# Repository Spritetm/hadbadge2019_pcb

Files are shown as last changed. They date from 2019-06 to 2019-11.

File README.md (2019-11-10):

Hackaday Supercon 2019 Badge: PCB/schematics
============================================

This repo contains the schematics and PCB artwork for the Hackaday Supercon 2019 badge. It isn't
as cleaned up yet as I want to be, but I hope it works as a reference. Note that there may be some
older text and other files floating around in the repo as well.

Known Issues
------------

There are some issues with the final release on the badge. They are collected here. If you find more,
feel free to open an issue.

* The PMOD connector I/O pins are reversed in contrast with the actual PMOD specification. As the
Vcc and GND pins are not affected, the connector is still PMOD-compatible. Only the badge silkscreen
and the schematics have the wrong pinout, the SoC and software is correct. 
(Ref [here](https://github.com/Spritetm/hadbadge2019_fpgasoc/issues/18) )

* The SAO connector is messed up: the SCL/SDA lines as well as GPIO1/GPIO2 are swapped. Both the net
names in the schematic as well as the silkscreen legend have this issue. Again, as Gnd and Vcc are in
the correct locations, this does not influence the functionality.

* The 8MHz clock oscillator is routed to a non-clock-capable GPIO. While Yosys/Nextpnr doesn't
have any real issues with this, the official lattice Diamond software will refuse to use this
as a clock pin. As a workaround, you may be able to route it to a clock-capable free pin, then use
the input from that pin as a clock. (Ref [here](https://github.com/Spritetm/hadbadge2019_fpgasoc/issues/12) )

* The buttons on the badge are not the intended 4.3mm model, but a larger one. This is caused 
by the wrong footprint; the footprint actually has the size of the button somewhere in the description, 
and the Chinese logistics guy dutifully went with that instead of the Taobao link or other things
indicating it needs to be 4.3mm.

* The badge cannot run from an USB power connection. This is intentional, as there's no nice way to
feed 5V into the system without adding a fair amount of extra power supply electronics.

License
-------

This hardware is licensed under [CC-BY-SA 3.0](http://creativecommons.org/licenses/by-sa/3.0/) 
A non-legalese summary would be that you're allowed to share and remix these designs, but you
should attribute me (Sprite_tm/Jeroen Domburg) for my work, and your new work should be licensed
under the same or a similar license. If this license doesn't work for your purposes, feel free
to contact me to discuss a different license. Also, optionally, if you do use these designs 
to build something, I would very much appreciate it if you could send me a copy.

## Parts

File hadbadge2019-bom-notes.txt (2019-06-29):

- J5 is for a LCD. This LCD is not in the BOM, but we would also like it to be in the quote. The
LCD is a ZYX Technology LQ032ALJV01 as sold here:
https://item.taobao.com/item.htm?spm=a1z09.2.0.0.67002e8dLTaCnr&id=43697704645&_u=h2c9d2uca587

- J11 is No Stuff.
- J3 is No Stuff
- R8, R19, R16 are No Stuff.

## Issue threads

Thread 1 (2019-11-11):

Need models for 3d output

softegg, 2019-11-11:
I'm trying to design an enclosure in advance of Hackaday Superconference, and although I can export a the PCB as a 3d model,  a lot of the 3d models are missing. It is much easier to construct an accurate enclosure if the parts that need holes or space in the enclosure, or button / switch tops are available and accurate.

A lot of the 3d models for parts like switches and the BGA part don’t seem to be part of the standard KiCAD distribution, and Googling isn’t turning them up.
So far, I’m looking at:
The buttons: SW_PUSH_6mm_H9.5mm.wrl The notes give a Taobao link, I suppose I should look it up, but it would be nice to not have to model it from scratch.
The connector for the screen (FH26W-45S-0.3SHW(60)) seems to have no model even listed, and there is not even a part on the board for the screen, so it seems. Found the part number (ZYX Technology LQ032ALJV01) in the BOM notes, so I looked that up. Although the manufacturer has a link, all it does is let you request a model.
The USB connector on J2: Connector_USB.3dshapes doesn’t contain USB_Micro-B_Amphenol, just other brands.
HDMI (!?) on J4 has no model. Seems to be Boom Precision HDMI-001.
The power switch doesn’t have a 3d model. I had to search to find what I think is a model number “Hroparts K3 12965”. I guess I have to build that one. Is it similar to some other part I might be able to find?
The BGA (not that important to model around, but nice for completeness): Lattice_caBGA-381_17.0x17.0mm_Layout20x20_P0.8mm_Ball0.4mm_Pad0.4mm_NSMD.wrl
The battery holders don’t have 3d models or model numbers, but they seem pretty generic, so maybe I can just use a standard one from something else and hope it fits.
The IR Receiver at U12 has no 3d model set. Seems to be RPM973-H11
Finally, speaker attached to J3, it would be good to know the part number

If some of these could be provided, it would make life a lot easier for me!

Spritetm, 2019-11-11:
FYI, I didn't add any 3d models to the PCB design myself, as I didn't need that feature. (I'd even have to look up how to do 3d models in the first place...) I'm afraid that what is in the repo is what you get...

softegg, 2019-11-11:
It just seemed like there were some parts that had models linked, implying that they exist, that aren't part of the standard distribution, and aren't included here.  Googling didn't turn them up. So I thought they might be living on your machine somehow, and perhaps you could share them?

Spritetm, 2019-11-11:
If they are, I have no idea how they got there, as I said I didn't add any models myself and my Kicad install is just a Debian apt-get install jobbie which I assume just pulls in the default libs.

softegg, 2019-11-11:
Can I get measurements on the display at least? Or a link to a datasheet with such? (And maybe the visible area?)
I've been googling, but I can't seem to find anything about LQ032ALJV01. I've found LQ35 and greater, but not this particular one.

Spritetm, 2019-11-11:
Yeah, the display is some obscure Chinesium, but hey, it was cheap and looks pretty good. I can probably give you measurements when I'm back home, this evening. Any other things you want me to put a pair of calipers against?

softegg, 2019-11-11:
Well, I've been substituting 3d models for other similar parts in absence of the actual parts and am pretty close to done save for the screen. I suspect that my HDMI port is probably too tall, so measuring that would be kind.
I'm currently using the model at https://grabcad.com/library/fci-hdmi-right-angle-header-1 in that place.
Also, I see in your notes that the manufacturer substituted a different button than the 4.3mm one you specified. Can you tell what size they actually used?

Spritetm, 2019-11-11:
HDMI connector has a datasheet [here](https://lcsc.com/product-detail/Audio-Video-Connectors_Boom-Precision-Elec-HDMI-001_C138388.html). (Link is on there, not sure if I can link it directly.)

LCD: Does [this sketch](http://j0h.nl/XPcB/full) give enough info? Note that the LCD is affixed to the PCB with double-sided foam tape of unknown thickness; I don't have any final badges here so I can't measure that.

softegg, 2019-11-13:
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
Made some progress!
How tall did the stem on the buttons end up being?
They seem quite close together...
I'm a little worried about the ports... they will be quite recessed in the case and I worry about the enclosure interfering with the cable housing.
I still need to model the backs of the buttons, lightpipe for LEDs, cartridge port and I/O access, but it is starting to look like something.

softegg, 2019-11-14:
Can I get the size of the stem on the buttons, please?
Also, is there a design for the cartridge PCB?

sphereinabox, 2019-11-15:
The buttons are 9.5mm or so tall when not clicked.

https://github.com/Spritetm/hadbadge2019_protoboard has the protoboard

softegg, 2019-11-15:
Thanks! I'll update the models. I'm already 3d printing them at the 4.3mm size, so I'll have to start the new print before I leave for Supercon. Maybe the current ones can be drilled out or something

Sorry I missed the presentation on them this morning; I was up till 6am working on getting this print going, and am still trying to finish the rest of the parts. I'll be there by 4pm, I hope!

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

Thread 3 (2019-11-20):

BOM / LCD part number

PTS93, 2019-11-20:
Do you have a full BOM?
Would love to look into possible replacement screens. Some specs and the drivers IC would be great.

Spritetm, 2019-11-21:
The display itself is an AUO H320QN01, I'm not 100% sure what version. Note that it probably does not 100% match anything you can find on the Internet, as I'm sure the chinese fab we got them from kinda assembled the display module from spare parts. I think the controller is a Samsung S6D05A1 chip; you probably want to compare that datasheet with the initialization sequence if you want to be 100% sure, though. The display originated [here](https://item.taobao.com/item.htm?spm=a1z09.2.0.0.67002e8dkyjVv9&id=43697704645&_u=l2c9d2uc25f4) but be aware that they changed the actual display to the Samsung controller later, so the pictures there are not matching what's on the badge.

PTS93, 2019-11-21:
Hm they do claim "Long-term supply". You mentioned at Supercon that they are likely not gonna be made that way again?

sqfmi, 2019-11-21:
I put together a BOM and cost estimate from the KiCad files: https://github.com/sqfmi/hadbadge2019_pcb/blob/master/hadbadge2019.csv

PTS93, 2019-11-21:
Awesome!

liamcadigan, 2020-02-17:
It would be great if we could get a copy of the BOM with part numbers instead of links to the website. Similar to the format described here https://www.inspectar.com/help-center-articles/creating-a-bom .

If that can be done we will upload it to the free version of inspectAR, an augmented reality tool for working on physical PCBs. Users will be able to request part details and view datasheets from Digi-Key natively within our application.

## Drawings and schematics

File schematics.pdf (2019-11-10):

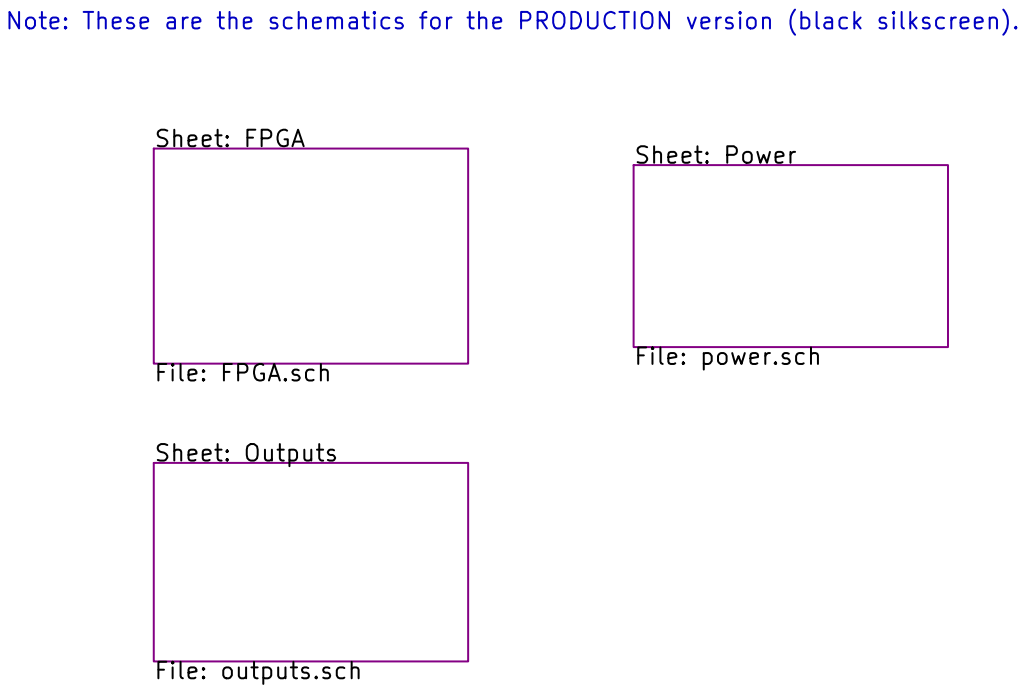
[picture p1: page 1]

Note: These are the schematics for the PRODUCTION version (black silkscreen).

File: hadbadge2019.sch Sheet: /
Id: 1/4 Title: Hackaday Badge 2019

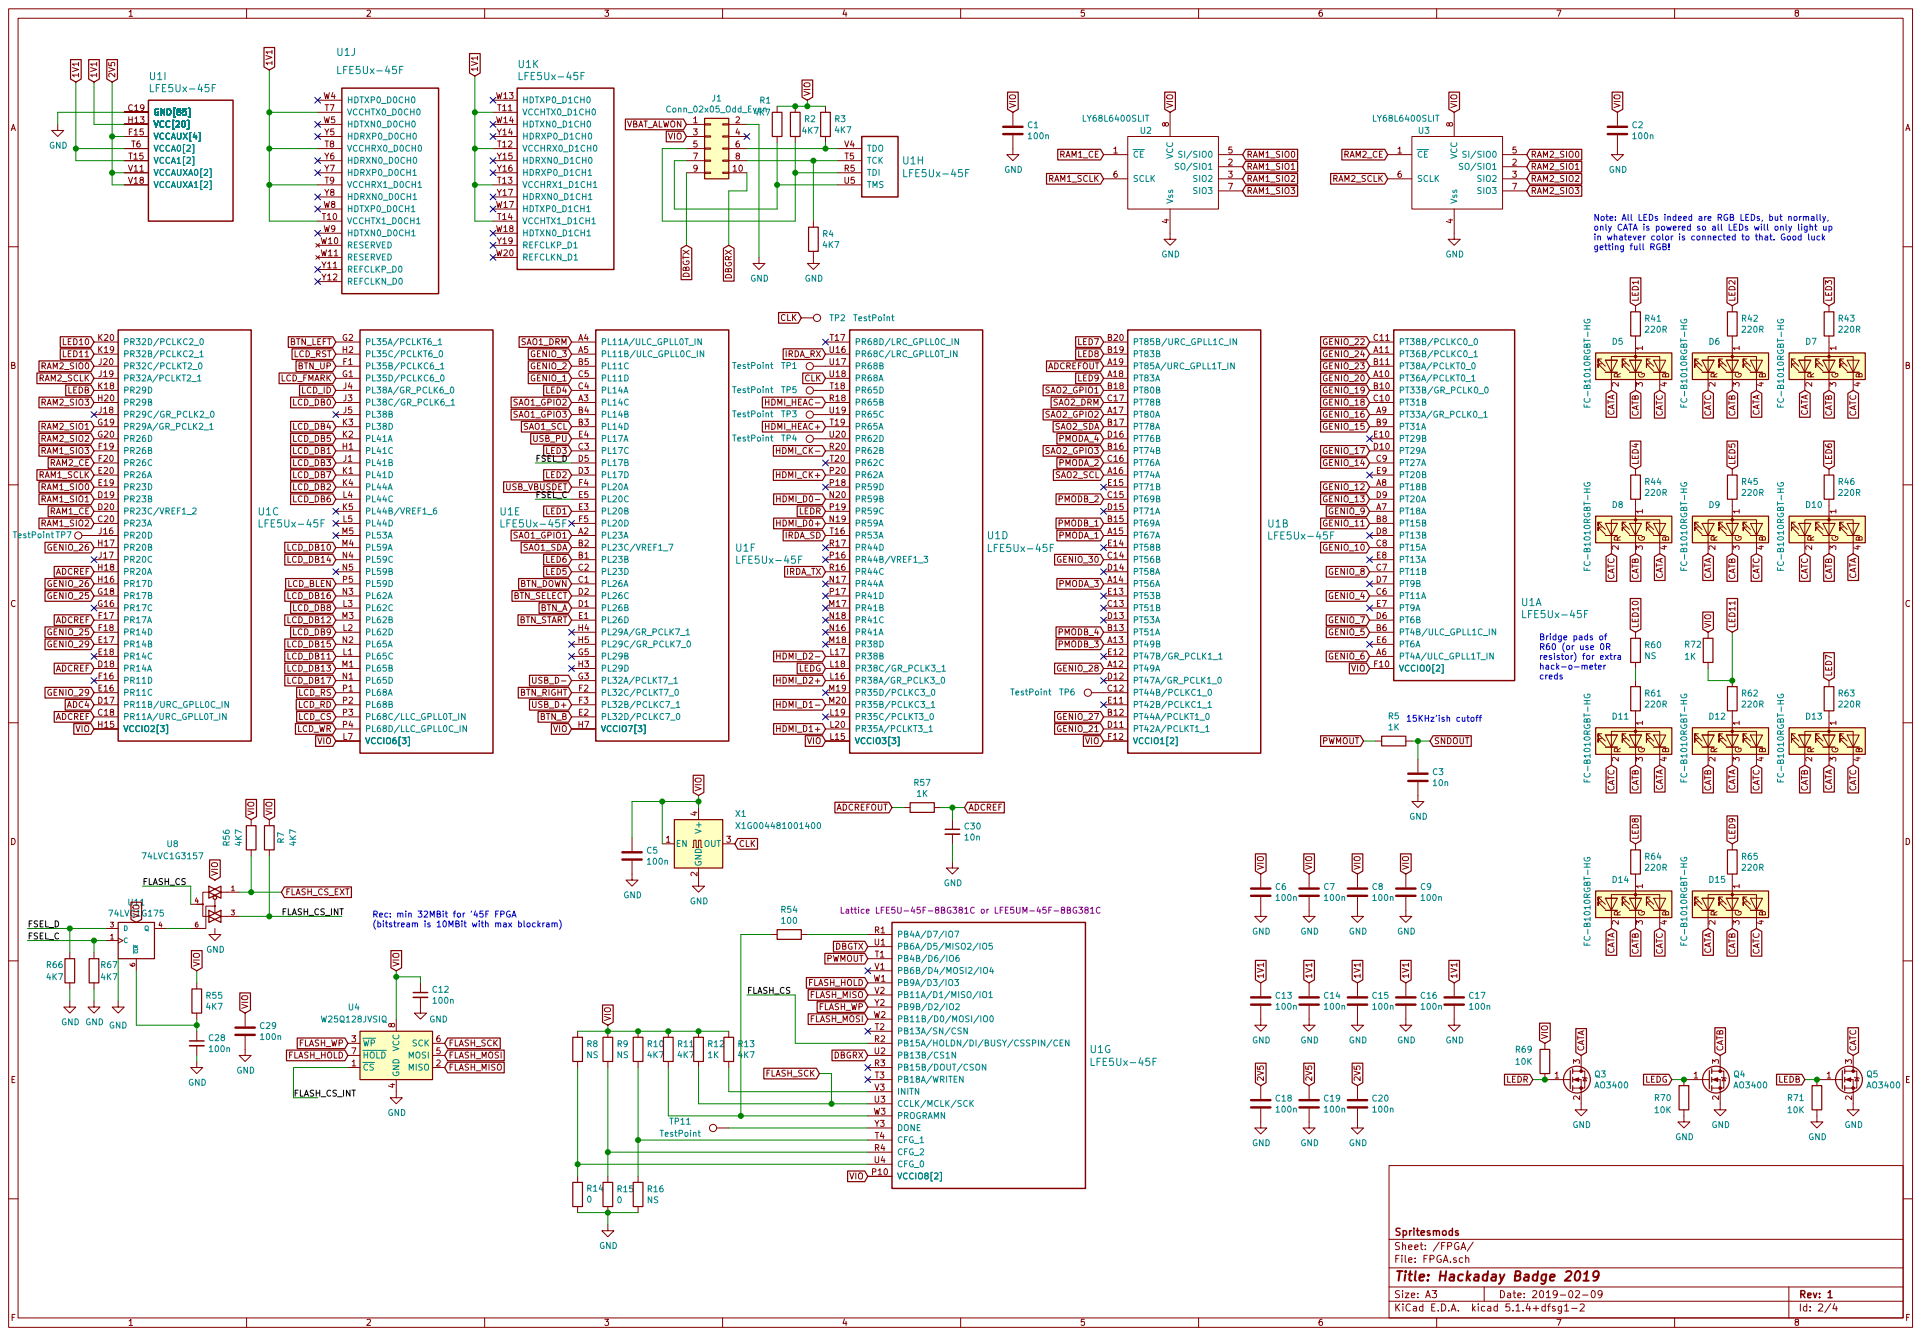
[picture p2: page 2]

Note: All LEDs indeed are RGB LEDs, but normally,
only CATA is powered so all LEDs will only light up
in whatever color is connected to that. Good luck getting full RGB!

Rec: min 32MBit for '45F FPGA

4 MOSI 5 SCK 6 HOLD 7 VCC

File: FPGA.sch Sheet: /FPGA/ Spritesmods C19

Id: 2/4 Title: Hackaday Badge 2019

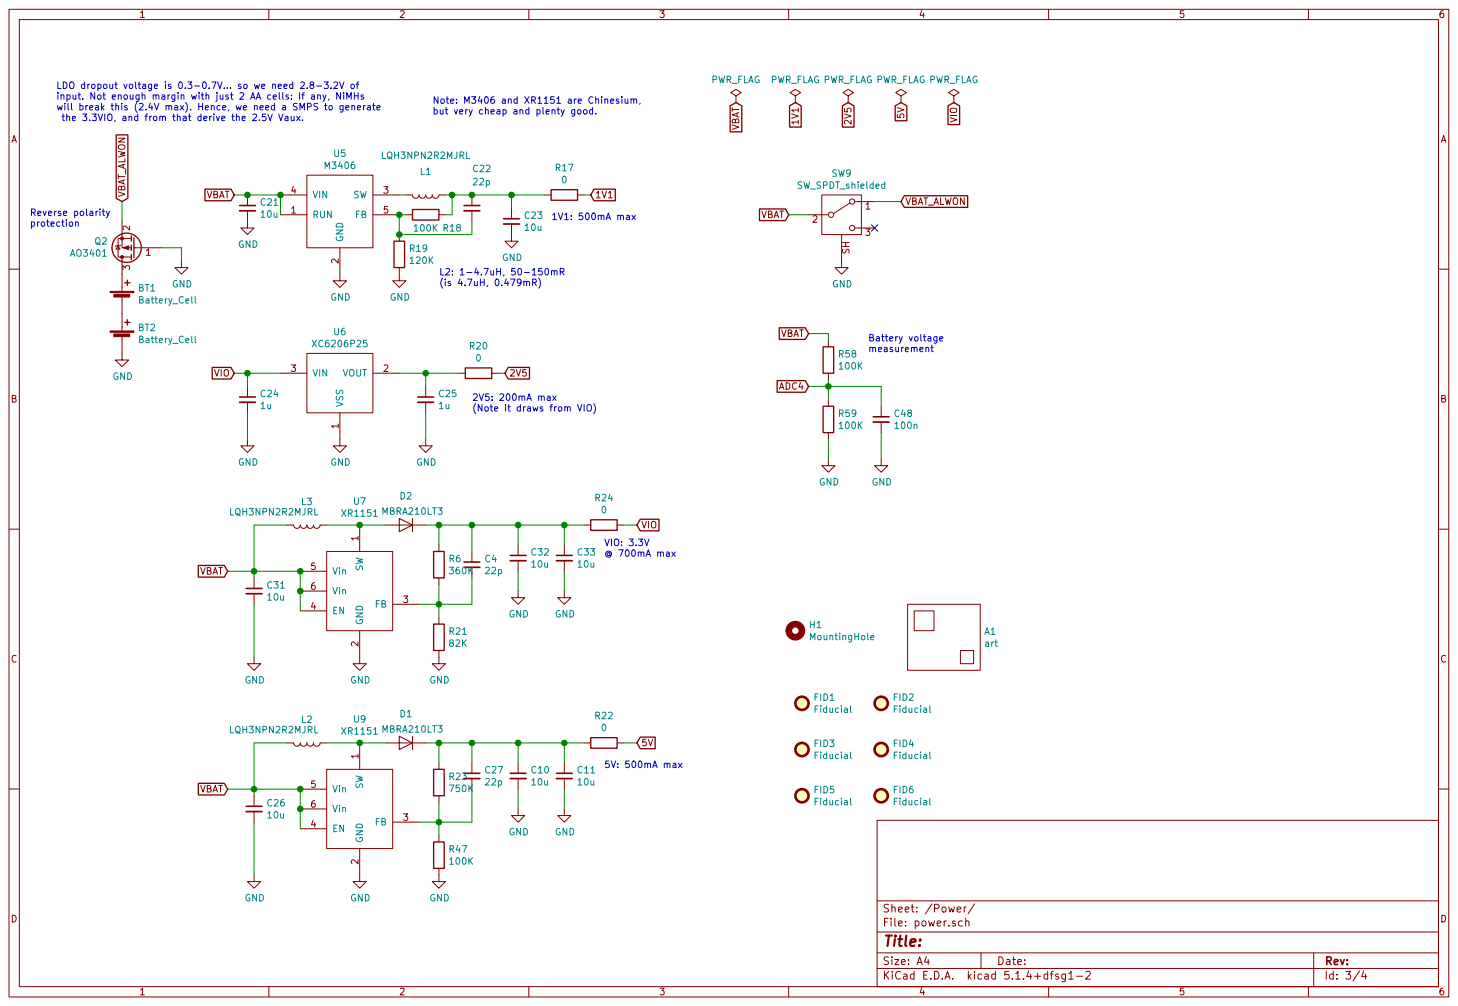
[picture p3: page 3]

LDO dropout voltage is 0.3-0.7V... so we need 2.8-3.2V of
input. Not enough margin with just 2 AA cells: If any, NiMHs
will break this (2.4V max). Hence, we need a SMPS to generate
the 3.3VIO, and from that derive the 2.5V Vaux.

PWR_FLAG PWR_FLAG PWR_FLAG
5V: 500mA max VIO: 3.3V @ 700mA max Note: M3406 and XR1151 are Chinesium, but very cheap and plenty good. 1V1: 500mA max 2V5: 200mA max

2 SW 3 VIN 4 FB 5 U5 M3406 GND GND
LQH3NPN2R2MJRL C24

(Note it draws from VIO) L2: 1-4.7uH, 50-150mR

2 FB 3 EN 4 Vin 5 Vin 6 U7 XR1151 GND
100K GND VSS

2 FB 3 EN 4 Vin 5 Vin 6 U9 XR1151 R23

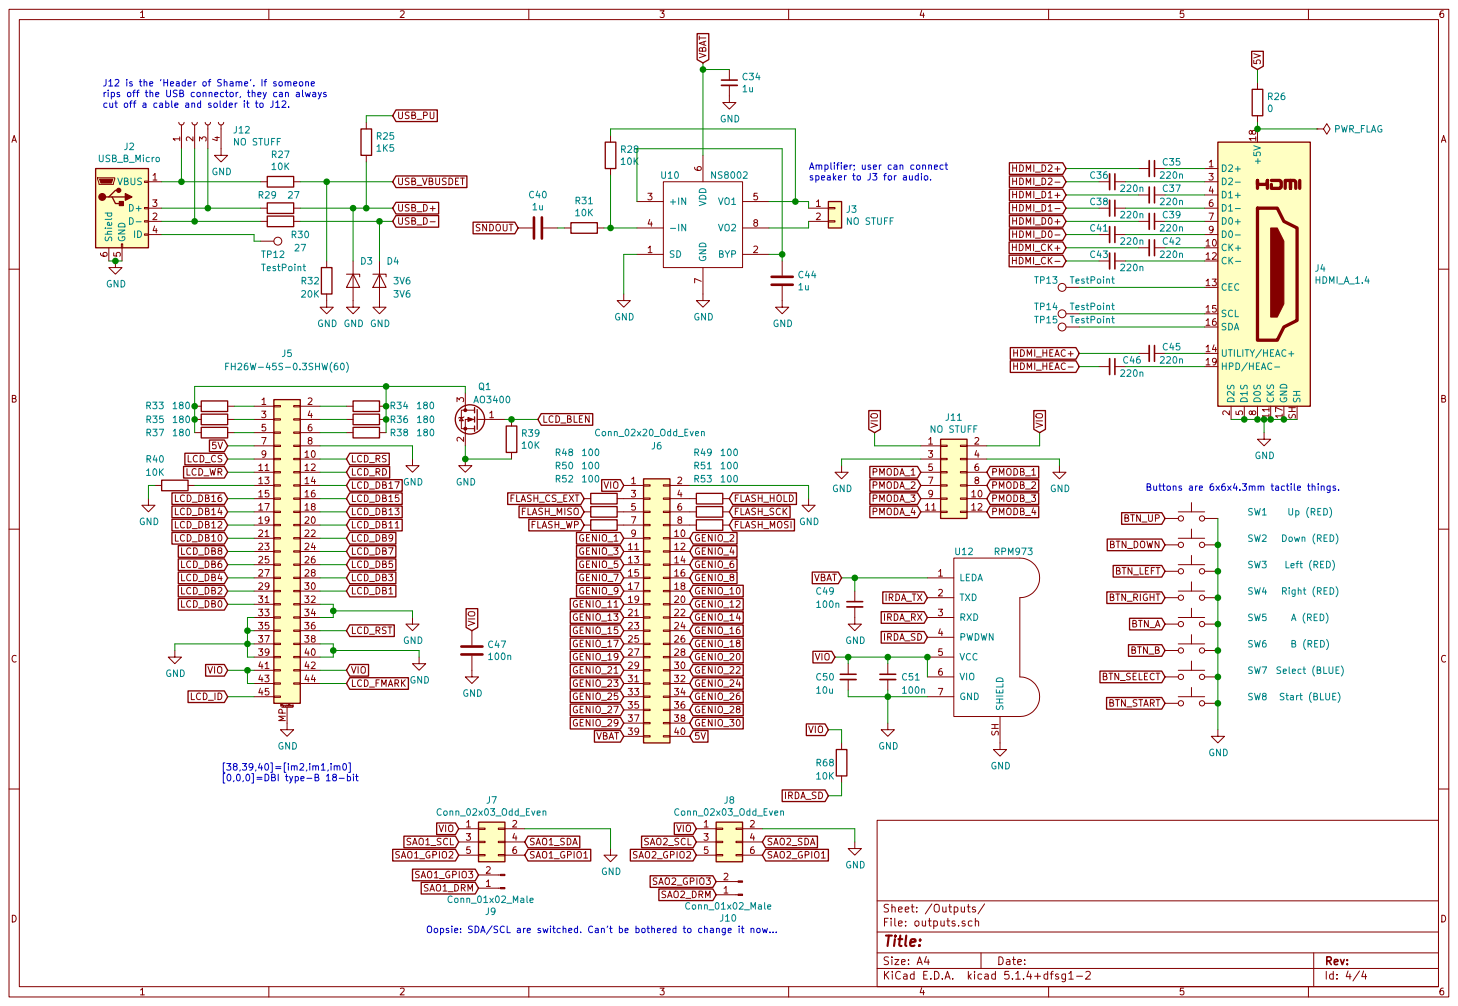
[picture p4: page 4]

J12 is the 'Header of Shame'. If someone
rips off the USB connector, they can always

Amplifier; user can connect
speaker to J3 for audio.

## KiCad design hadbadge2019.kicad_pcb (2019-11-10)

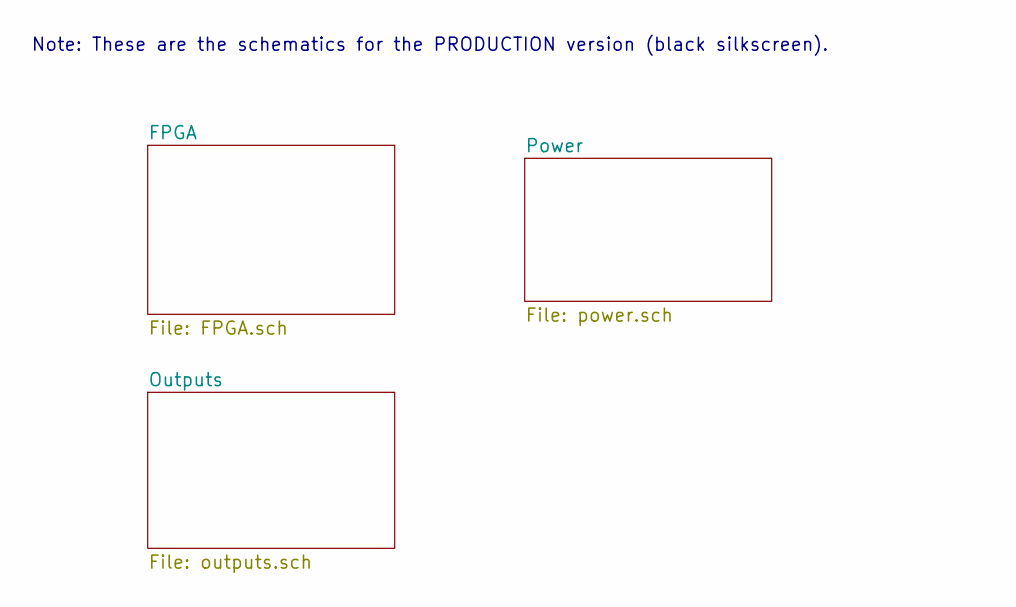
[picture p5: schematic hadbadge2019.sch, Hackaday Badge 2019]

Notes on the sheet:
Note: These are the schematics for the PRODUCTION version (black silkscreen).

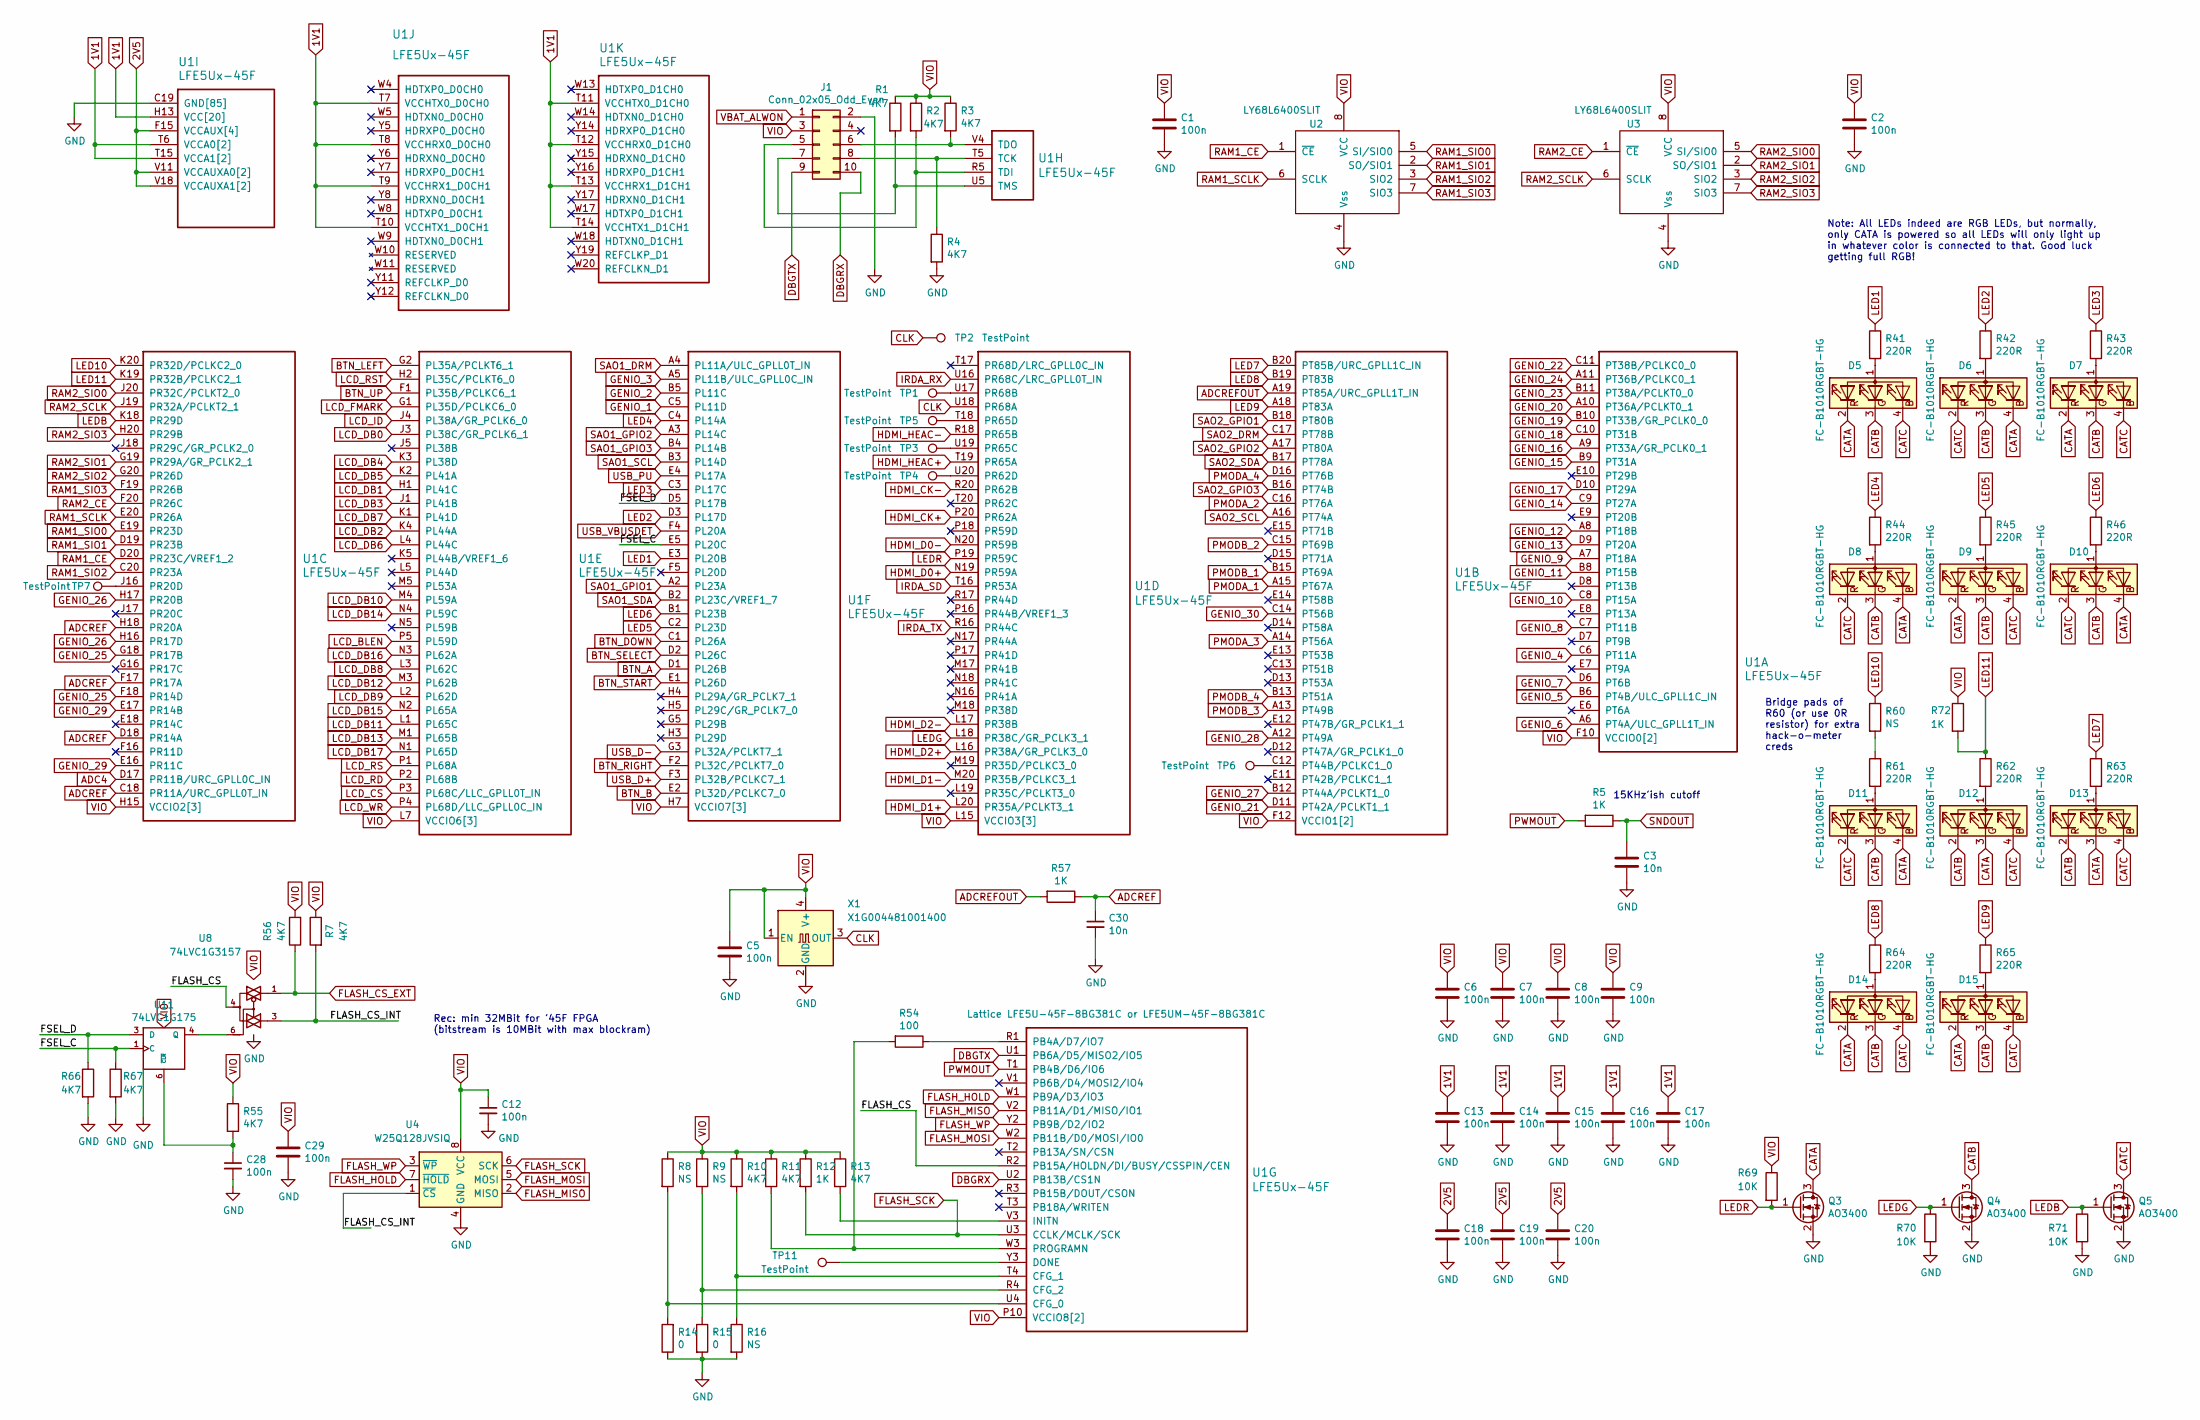
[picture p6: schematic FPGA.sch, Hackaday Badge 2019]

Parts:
C1, C2, C5, C6, C7, C8, C9, C12, C13, C14, C15, C16, C17, C18, C19, C20, C28, C29: 100n; C_0603_1608Metric
C3, C30: 10n; C_0603_1608Metric
D5, D6, D7, D8, D9, D10, D11, D12, D13, D14, D15: FC-B1010RGBT-HG
J1: Conn_02x05_Odd_Even; PinHeader_2x05_P2.54mm_Vertical
Q3, Q4, Q5: AO3400; SOT-23
R1, R2, R3, R4, R7, R10, R11, R13, R55, R56, R66, R67: 4K7; R_0603_1608Metric
R5, R12, R57, R72: 1K; R_0603_1608Metric
R8, R9, R16, R60: NS; R_0603_1608Metric
R14, R15: 0; R_0603_1608Metric
R41, R42, R43, R44, R45, R46, R61, R62, R63, R64, R65: 220R; R_0603_1608Metric
R54: 100; R_0603_1608Metric
R69, R70, R71: 10K; R_0603_1608Metric
TP1, TP2, TP3, TP4, TP5, TP6, TP7, TP11: TestPoint; TestPoint_Pad_D1.0mm
U1: LFE5Ux-45F; Lattice_caBGA-381_17.0x17.0mm_Layout20x20_P0.8mm_Ball0.4mm_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
U2, U3: LY68L6400SLIT; SSOP-8_3.9x5.05mm_P1.27mm
U4: W25Q128JVSIQ; SSOP-8_5.25x5.24mm_P1.27mm
U8: 74LVC1G3157; SOT-23-6
U11: 74LVC1G175; SOT-23-6
X1: X1G004481001400; Seiko_fp_crystal_SMD_7050-4Pin_7.0x5.0mm

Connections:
1V1: C13.1, C14.1, C15.1, C16.1, C17.1, U1.H8 (VCC[20]), U1.H9 (VCC[20]), U1.H10 (VCC[20]), U1.H11 (VCC[20]), U1.H12 (VCC[20]), U1.H13 (VCC[20]), U1.J8 (VCC[20]), U1.J13 (VCC[20]), U1.K8 (VCC[20]), U1.K13 (VCC[20]), U1.L8 (VCC[20]), U1.L13 (VCC[20]), U1.M8 (VCC[20]), U1.M13 (VCC[20]), U1.N8 (VCC[20]), U1.N9 (VCC[20]), U1.N10 (VCC[20]), U1.N11 (VCC[20]), U1.N12 (VCC[20]), U1.N13 (VCC[20]), U1.T6 (VCCA0[2]), U1.T7 (VCCHTX0_D0CH0), U1.T8 (VCCHRX0_D0CH0), U1.T9 (VCCHRX1_D0CH1), U1.T10 (VCCHTX1_D0CH1), U1.T11 (VCCHTX0_D1CH0), U1.T12 (VCCHRX0_D1CH0), U1.T13 (VCCHRX1_D1CH1), U1.T14 (VCCHTX1_D1CH1), U1.T15 (VCCA1[2]), U1.U6 (VCCA0[2]), U1.U15 (VCCA1[2]); also elsewhere on the board
2V5: C18.1, C19.1, C20.1, U1.F6 (VCCAUX[4]), U1.F15 (VCCAUX[4]), U1.P6 (VCCAUX[4]), U1.P15 (VCCAUX[4]), U1.V10 (VCCAUXA0[2]), U1.V11 (VCCAUXA0[2]), U1.V17 (VCCAUXA1[2]), U1.V18 (VCCAUXA1[2]); also elsewhere on the board
/FPGA/FLASH_CS: U1.R2 (PB15A/HOLDN/DI/BUSY/CSSPIN/CEN), U8.4
/FPGA/FLASH_CS_INT: R7.2, U4.1 (~CS), U8.3
/FPGA/FSEL_C: R67.1, U1.E5 (PL20C), U11.1 (C)
/FPGA/FSEL_D: R66.1, U1.D5 (PL17B), U11.3 (D)
ADC4: U1.D17 (PR11B/URC_GPLL0C_IN); also elsewhere on the board
ADCREF: C30.1, R57.1, U1.C18 (PR11A/URC_GPLL0T_IN), U1.D18 (PR14A), U1.F17 (PR17A), U1.H18 (PR20A)
ADCREFOUT: R57.2, U1.A19 (PT85A/URC_GPLL1T_IN)
BTN_A: U1.D1 (PL26B); also elsewhere on the board
BTN_B: U1.E2 (PL32D/PCLKC7_0); also elsewhere on the board
BTN_DOWN: U1.C1 (PL26A); also elsewhere on the board
BTN_LEFT: U1.G2 (PL35A/PCLKT6_1); also elsewhere on the board
BTN_RIGHT: U1.F2 (PL32C/PCLKT7_0); also elsewhere on the board
BTN_SELECT: U1.D2 (PL26C); also elsewhere on the board
BTN_START: U1.E1 (PL26D); also elsewhere on the board
BTN_UP: U1.F1 (PL35B/PCLKC6_1); also elsewhere on the board
CATA: D5.2 (RK), D6.4 (BK), D7.2 (RK), D8.4 (BK), D9.2 (RK), D10.4 (BK), D11.4 (BK), D12.3 (GK), D13.3 (GK), D14.2 (RK), D15.2 (RK), Q3.3 (D)
CATB: D5.3 (GK), D6.3 (GK), D7.3 (GK), D8.3 (GK), D9.3 (GK), D10.3 (GK), D11.3 (GK), D12.2 (RK), D13.2 (RK), D14.3 (GK), D15.3 (GK), Q4.3 (D)
CATC: D5.4 (BK), D6.2 (RK), D7.4 (BK), D8.2 (RK), D9.4 (BK), D10.2 (RK), D11.2 (RK), D12.4 (BK), D13.4 (BK), D14.4 (BK), D15.4 (BK), Q5.3 (D)
CLK: TP2.1, U1.U18 (PR68A), X1.3 (OUT)
DBGRX: J1.10, U1.U2 (PB13B/CS1N)
DBGTX: J1.9, U1.U1 (PB6A/D5/MISO2/IO5)
FLASH_CS_EXT: R56.1, U8.1; also elsewhere on the board
FLASH_HOLD: U1.W1 (PB9A/D3/IO3), U4.7 (~HOLD); also elsewhere on the board
FLASH_MISO: U1.V2 (PB11A/D1/MISO/IO1), U4.2 (MISO); also elsewhere on the board
FLASH_MOSI: U1.W2 (PB11B/D0/MOSI/IO0), U4.5 (MOSI); also elsewhere on the board
FLASH_SCK: R12.2, U1.U3 (CCLK/MCLK/SCK), U4.6 (SCK); also elsewhere on the board
FLASH_WP: U1.Y2 (PB9B/D2/IO2), U4.3 (~WP); also elsewhere on the board
GENIO_1: U1.C5 (PL11D); also elsewhere on the board
GENIO_2: U1.B5 (PL11C); also elsewhere on the board
GENIO_3: U1.A5 (PL11B/ULC_GPLL0C_IN); also elsewhere on the board
GENIO_4: U1.C6 (PT11A); also elsewhere on the board
GENIO_5: U1.B6 (PT4B/ULC_GPLL1C_IN); also elsewhere on the board
GENIO_6: U1.A6 (PT4A/ULC_GPLL1T_IN); also elsewhere on the board
GENIO_7: U1.D6 (PT6B); also elsewhere on the board
GENIO_8: U1.C7 (PT11B); also elsewhere on the board
GENIO_9: U1.A7 (PT18A); also elsewhere on the board
GENIO_10: U1.C8 (PT15A); also elsewhere on the board
GENIO_11: U1.B8 (PT15B); also elsewhere on the board
GENIO_12: U1.A8 (PT18B); also elsewhere on the board
GENIO_13: U1.D9 (PT20A); also elsewhere on the board
GENIO_14: U1.C9 (PT27A); also elsewhere on the board
GENIO_15: U1.B9 (PT31A); also elsewhere on the board
GENIO_16: U1.A9 (PT33A/GR_PCLK0_1); also elsewhere on the board
GENIO_17: U1.D10 (PT29A); also elsewhere on the board
GENIO_18: U1.C10 (PT31B); also elsewhere on the board
GENIO_19: U1.B10 (PT33B/GR_PCLK0_0); also elsewhere on the board
GENIO_20: U1.A10 (PT36A/PCLKT0_1); also elsewhere on the board
GENIO_21: U1.D11 (PT42A/PCLKT1_1); also elsewhere on the board
GENIO_22: U1.C11 (PT38B/PCLKC0_0); also elsewhere on the board
GENIO_23: U1.B11 (PT38A/PCLKT0_0); also elsewhere on the board
GENIO_24: U1.A11 (PT36B/PCLKC0_1); also elsewhere on the board
GENIO_25: U1.F18 (PR14D), U1.G18 (PR17B); also elsewhere on the board
GENIO_26: U1.H16 (PR17D), U1.H17 (PR20B); also elsewhere on the board
GENIO_27: U1.B12 (PT44A/PCLKT1_0); also elsewhere on the board
GENIO_28: U1.A12 (PT49A); also elsewhere on the board
GENIO_29: U1.E16 (PR11C), U1.E17 (PR14B); also elsewhere on the board
GENIO_30: U1.C14 (PT56B); also elsewhere on the board
GND: C1.2, C2.2, C3.2, C5.2, C6.2, C7.2, C8.2, C9.2, C12.2, C13.2, C14.2, C15.2, C16.2, C17.2, C18.2, C19.2, C20.2, C28.2, C29.2, C30.2, J1.2, Q3.2 (S), Q4.2 (S), Q5.2 (S), R4.2, R14.1, R15.2, R16.2, R66.2, R67.2, R70.2, R71.2, U1.B7 (GND[85]), U1.B14 (GND[85]), U1.C19 (GND[85]), U1.D4 (GND[85]), U1.F7 (GND[85]), U1.F8 (GND[85]), U1.F13 (GND[85]), U1.F14 (GND[85]), U1.G4 (GND[85]), U1.G6 (GND[85]), U1.G7 (GND[85]), U1.G8 (GND[85]), U1.G9 (GND[85]), U1.G10 (GND[85]), U1.G11 (GND[85]), U1.G12 (GND[85]), U1.G13 (GND[85]), U1.G14 (GND[85]), U1.G15 (GND[85]), U1.G17 (GND[85]), U1.H19 (GND[85]), U1.J2 (GND[85]), U1.J7 (GND[85]), U1.J9 (GND[85]), U1.J10 (GND[85]), U1.J11 (GND[85]), U1.J12 (GND[85]), U1.J14 (GND[85]), U1.K6 (GND[85]), U1.K7 (GND[85]), U1.K9 (GND[85]), U1.K10 (GND[85]), U1.K11 (GND[85]), U1.K12 (GND[85]), U1.K14 (GND[85]), U1.K15 (GND[85]), U1.L9 (GND[85]), U1.L10 (GND[85]), U1.L11 (GND[85]), U1.L12 (GND[85]), U1.M2 (GND[85]), U1.M7 (GND[85]), U1.M9 (GND[85]), U1.M10 (GND[85]), U1.M11 (GND[85]), U1.M12 (GND[85]), U1.M14 (GND[85]), U1.M16 (GND[85]), U1.N6 (GND[85]), U1.N7 (GND[85]), U1.N14 (GND[85]), U1.N15 (GND[85]), U1.P7 (GND[85]), U1.P8 (GND[85]), U1.P11 (GND[85]), U1.P12 (GND[85]), U1.P13 (GND[85]), U1.P14 (GND[85]), U1.R19 (GND[85]), U1.U7 (GND[85]), U1.U8 (GND[85]), U1.U9 (GND[85]), U1.U10 (GND[85]), U1.U11 (GND[85]), U1.U12 (GND[85]), U1.U13 (GND[85]), U1.U14 (GND[85]), U1.V5 (GND[85]), U1.V6 (GND[85]), U1.V7 (GND[85]), U1.V8 (GND[85]), U1.V9 (GND[85]), U1.V12 (GND[85]), U1.V13 (GND[85]), U1.V14 (GND[85]), U1.V15 (GND[85]), U1.V16 (GND[85]), U1.V19 (GND[85]), U1.V20 (GND[85]), U1.W6 (GND[85]), U1.W7 (GND[85]), U1.W12 (GND[85]), U1.W15 (GND[85]), U1.W16 (GND[85]), U1.W19 (GND[85]), U2.4 (Vss), U3.4 (Vss), U4.4 (GND), U8.2 (GND), U11.2 (GND), X1.2 (GND); also elsewhere on the board
HDMI_CK+: U1.P20 (PR62A); also elsewhere on the board
HDMI_CK-: U1.R20 (PR62B); also elsewhere on the board
HDMI_D0+: U1.N19 (PR59A); also elsewhere on the board
HDMI_D0-: U1.N20 (PR59B); also elsewhere on the board
HDMI_D1+: U1.L20 (PR35A/PCLKT3_1); also elsewhere on the board
HDMI_D1-: U1.M20 (PR35B/PCLKC3_1); also elsewhere on the board
HDMI_D2+: U1.L16 (PR38A/GR_PCLK3_0); also elsewhere on the board
HDMI_D2-: U1.L17 (PR38B); also elsewhere on the board
HDMI_HEAC+: U1.T19 (PR65A); also elsewhere on the board
HDMI_HEAC-: U1.R18 (PR65B); also elsewhere on the board
IRDA_RX: U1.U16 (PR68C/LRC_GPLL0T_IN); also elsewhere on the board
IRDA_SD: U1.T16 (PR53A); also elsewhere on the board
IRDA_TX: U1.R16 (PR44C); also elsewhere on the board
LCD_BLEN: U1.P5 (PL59D); also elsewhere on the board
LCD_CS: U1.P3 (PL68C/LLC_GPLL0T_IN); also elsewhere on the board
LCD_DB0: U1.J3 (PL38C/GR_PCLK6_1); also elsewhere on the board
LCD_DB1: U1.H1 (PL41C); also elsewhere on the board
LCD_DB2: U1.K4 (PL44A); also elsewhere on the board
LCD_DB3: U1.J1 (PL41B); also elsewhere on the board
LCD_DB4: U1.K3 (PL38D); also elsewhere on the board
LCD_DB5: U1.K2 (PL41A); also elsewhere on the board
LCD_DB6: U1.L4 (PL44C); also elsewhere on the board
LCD_DB7: U1.K1 (PL41D); also elsewhere on the board
LCD_DB8: U1.L3 (PL62C); also elsewhere on the board
LCD_DB9: U1.L2 (PL62D); also elsewhere on the board
LCD_DB10: U1.M4 (PL59A); also elsewhere on the board
LCD_DB11: U1.L1 (PL65C); also elsewhere on the board
LCD_DB12: U1.M3 (PL62B); also elsewhere on the board
LCD_DB13: U1.M1 (PL65B); also elsewhere on the board
LCD_DB14: U1.N4 (PL59C); also elsewhere on the board
LCD_DB15: U1.N2 (PL65A); also elsewhere on the board
LCD_DB16: U1.N3 (PL62A); also elsewhere on the board
LCD_DB17: U1.N1 (PL65D); also elsewhere on the board
LCD_FMARK: U1.G1 (PL35D/PCLKC6_0); also elsewhere on the board
LCD_ID: U1.J4 (PL38A/GR_PCLK6_0); also elsewhere on the board
LCD_RD: U1.P2 (PL68B); also elsewhere on the board
LCD_RS: U1.P1 (PL68A); also elsewhere on the board
LCD_RST: U1.H2 (PL35C/PCLKT6_0); also elsewhere on the board
LCD_WR: U1.P4 (PL68D/LLC_GPLL0C_IN); also elsewhere on the board
LED1: R41.1, U1.E3 (PL20B)
LED2: R42.1, U1.D3 (PL17D)
LED3: R43.1, U1.C3 (PL17C)
LED4: R44.1, U1.C4 (PL14A)
LED5: R45.1, U1.C2 (PL23D)
LED6: R46.1, U1.B1 (PL23B)
LED7: R63.1, U1.B20 (PT85B/URC_GPLL1C_IN)
LED8: R64.1, U1.B19 (PT83B)
LED9: R65.1, U1.A18 (PT83A)
LED10: R60.1, U1.K20 (PR32D/PCLKC2_0)
LED11: R62.1, R72.2, U1.K19 (PR32B/PCLKC2_1)
LEDB: Q5.1 (G), R71.1, U1.K18 (PR29D)
LEDG: Q4.1 (G), R70.1, U1.L18 (PR38C/GR_PCLK3_1)
LEDR: Q3.1 (G), R69.2, U1.P19 (PR59C)
unnamed: C28.1, R55.2, U11.6 (~CLR)
unnamed: D5.1 (A), R41.2
unnamed: D6.1 (A), R42.2
unnamed: D7.1 (A), R43.2
unnamed: D8.1 (A), R44.2
unnamed: D9.1 (A), R45.2
unnamed: D10.1 (A), R46.2
unnamed: D11.1 (A), R61.2
unnamed: D12.1 (A), R62.2
unnamed: D13.1 (A), R63.2
unnamed: D14.1 (A), R64.2
unnamed: D15.1 (A), R65.2
unnamed: J1.5, R2.2, U1.R5 (TDI)
unnamed: J1.6, R3.2, U1.V4 (TDO)
unnamed: J1.7, R1.2, U1.U5 (TMS)
unnamed: J1.8, R4.1, U1.T5 (TCK)
unnamed: R10.2, R16.1, U1.T4 (CFG_1)
unnamed: R11.2, R54.2, U1.W3 (PROGRAMN)
unnamed: R13.2, U1.V3 (INITN)
unnamed: R8.2, R14.2, U1.U4 (CFG_0)
unnamed: R9.2, R15.1, U1.R4 (CFG_2)
unnamed: R54.1, U1.R1 (PB4A/D7/IO7)
unnamed: R60.2, R61.1
unnamed: TP1.1, U1.U17 (PR68B)
unnamed: TP3.1, U1.U19 (PR65C)
unnamed: TP4.1, U1.U20 (PR62D)
unnamed: TP5.1, U1.T18 (PR65D)
unnamed: TP6.1, U1.C12 (PT44B/PCLKC1_0)
unnamed: TP7.1, U1.J16 (PR20D)
unnamed: TP11.1, U1.Y3 (DONE)
unnamed: U8.6, U11.4 (Q)
PMODA_1: U1.A15 (PT67A); also elsewhere on the board
PMODA_2: U1.C16 (PT76A); also elsewhere on the board
PMODA_3: U1.A14 (PT56A); also elsewhere on the board
PMODA_4: U1.D16 (PT76B); also elsewhere on the board
PMODB_1: U1.B15 (PT69A); also elsewhere on the board
PMODB_2: U1.C15 (PT69B); also elsewhere on the board
PMODB_3: U1.A13 (PT49B); also elsewhere on the board
PMODB_4: U1.B13 (PT51A); also elsewhere on the board
PWMOUT: R5.2, U1.T1 (PB4B/D6/IO6)
RAM1_CE: U1.D20 (PR23C/VREF1_2), U2.1 (~CE)
RAM1_SCLK: U1.E20 (PR26A), U2.6 (SCLK)
RAM1_SIO0: U1.E19 (PR23D), U2.5 (SI/SIO0)
RAM1_SIO1: U1.D19 (PR23B), U2.2 (SO/SIO1)
RAM1_SIO2: U1.C20 (PR23A), U2.3 (SIO2)
RAM1_SIO3: U1.F19 (PR26B), U2.7 (SIO3)
RAM2_CE: U1.F20 (PR26C), U3.1 (~CE)
RAM2_SCLK: U1.J19 (PR32A/PCLKT2_1), U3.6 (SCLK)
RAM2_SIO0: U1.J20 (PR32C/PCLKT2_0), U3.5 (SI/SIO0)
RAM2_SIO1: U1.G19 (PR29A/GR_PCLK2_1), U3.2 (SO/SIO1)
RAM2_SIO2: U1.G20 (PR26D), U3.3 (SIO2)
RAM2_SIO3: U1.H20 (PR29B), U3.7 (SIO3)
SAO1_DRM: U1.A4 (PL11A/ULC_GPLL0T_IN); also elsewhere on the board
SAO1_GPIO1: U1.A2 (PL23A); also elsewhere on the board
SAO1_GPIO2: U1.A3 (PL14C); also elsewhere on the board
SAO1_GPIO3: U1.B4 (PL14B); also elsewhere on the board
SAO1_SCL: U1.B3 (PL14D); also elsewhere on the board
SAO1_SDA: U1.B2 (PL23C/VREF1_7); also elsewhere on the board
SAO2_DRM: U1.C17 (PT78B); also elsewhere on the board
SAO2_GPIO1: U1.B18 (PT80B); also elsewhere on the board
SAO2_GPIO2: U1.A17 (PT80A); also elsewhere on the board
SAO2_GPIO3: U1.B16 (PT74B); also elsewhere on the board
SAO2_SCL: U1.A16 (PT74A); also elsewhere on the board
SAO2_SDA: U1.B17 (PT78A); also elsewhere on the board
SNDOUT: C3.1, R5.1; also elsewhere on the board
USB_D+: U1.F3 (PL32B/PCLKC7_1); also elsewhere on the board
USB_D-: U1.G3 (PL32A/PCLKT7_1); also elsewhere on the board
USB_PU: U1.E4 (PL17A); also elsewhere on the board
USB_VBUSDET: U1.F4 (PL20A); also elsewhere on the board
VBAT_ALWON: J1.1; also elsewhere on the board
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

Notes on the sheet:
Rec: min 32MBit for '45F FPGA (bitstream is 10MBit with max blockram)
15KHz'ish cutoff
Note: All LEDs indeed are RGB LEDs, but normally, only CATA is powered so all LEDs will only light up in whatever color is connected to that. Good luck getting full RGB!
Bridge pads of R60 (or use 0R resistor) for extra hack-o-meter creds

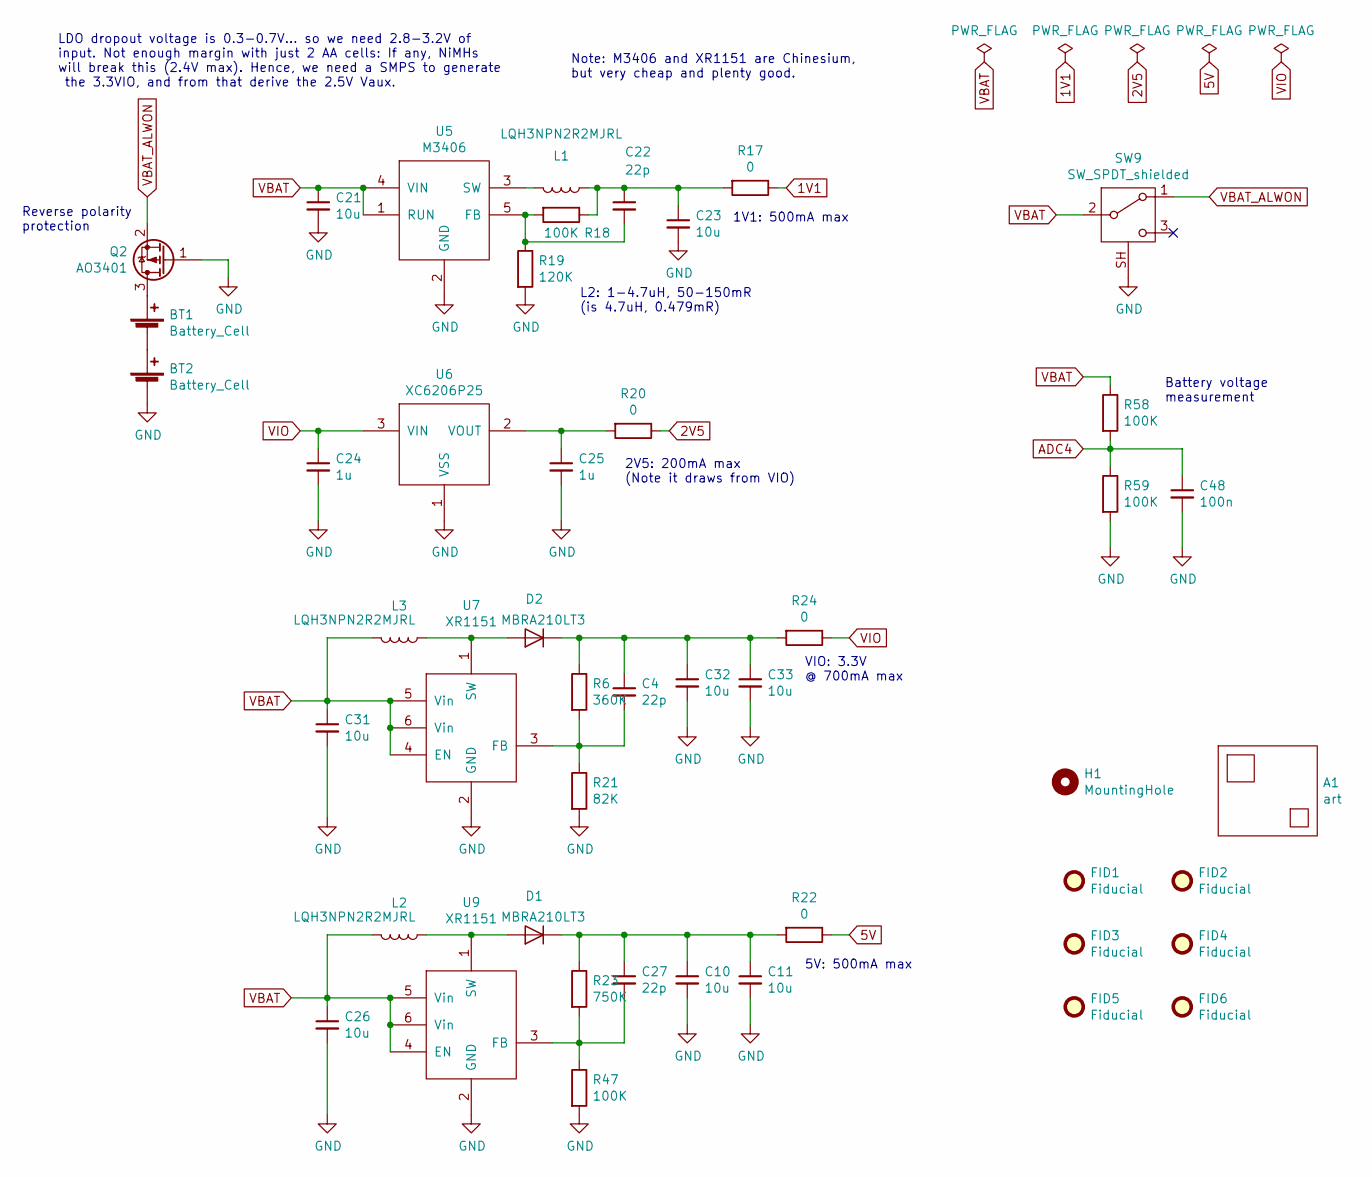
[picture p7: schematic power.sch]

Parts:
A1: art; badge_art
BT1, BT2: Battery_Cell; battery_holder_1xAA
C4, C22, C27: 22p; C_0603_1608Metric
C10, C11, C21, C23, C26, C31, C32, C33: 10u; C_0805_2012Metric
C24, C25: 1u; C_0603_1608Metric
C48: 100n; C_0603_1608Metric
D1, D2: MBRA210LT3; D_SMA
FID1, FID2, FID3, FID4, FID5, FID6: Fiducial; Fiducial_0.75mm_Mask1.5mm
H1: MountingHole; MountingHole_3.5mm
L1, L2, L3: LQH3NPN2R2MJRL; Murata_1212
Q2: AO3401; SOT-23
R6: 360K; R_0603_1608Metric
R17, R20, R22, R24: 0; R_0603_1608Metric
R18, R47, R58, R59: 100K; R_0603_1608Metric
R19: 120K; R_0603_1608Metric
R21: 82K; R_0603_1608Metric
R23: 750K; R_0603_1608Metric
SW9: SW_SPDT_shielded; Korean_Hroparts_K3_1296S
U5: M3406; SOT-23-5
U6: XC6206P25; SOT-23
U7, U9: XR1151; SOT-23-6

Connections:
1V1: R17.1; also elsewhere on the board
2V5: R20.1; also elsewhere on the board
5V: R22.1; also elsewhere on the board
ADC4: C48.1, R58.2, R59.1; also elsewhere on the board
GND: BT2.2 (-), C10.2, C11.2, C21.2, C23.2, C24.2, C25.2, C26.2, C31.2, C32.2, C33.2, C48.2, Q2.1 (G), R19.2, R21.2, R47.2, R59.2, SW9.SH, U5.2 (GND), U6.1 (VSS), U7.2 (GND), U9.2 (GND); also elsewhere on the board
unnamed: BT1.1 (+), Q2.3 (D)
unnamed: BT1.2 (-), BT2.1 (+)
unnamed: C4.2, R6.2, R21.1, U7.3 (FB)
unnamed: C10.1, C11.1, C27.1, D1.1 (K), R22.2, R23.1
unnamed: C22.1, C23.1, L1.1, R17.2, R18.1
unnamed: C22.2, R18.2, R19.1, U5.5 (FB)
unnamed: C25.1, R20.2, U6.2 (VOUT)
unnamed: C27.2, R23.2, R47.1, U9.3 (FB)
unnamed: C4.1, C32.1, C33.1, D2.1 (K), R6.1, R24.2
unnamed: D1.2 (A), L2.1, U9.1 (SW)
unnamed: D2.2 (A), L3.1, U7.1 (SW)
unnamed: L1.2, U5.3 (SW)
VBAT: C21.1, C26.1, C31.1, L2.2, L3.2, R58.1, SW9.2 (B), U5.1 (RUN), U5.4 (VIN), U7.4 (EN), U7.5 (Vin), U7.6 (Vin), U9.4 (EN), U9.5 (Vin), U9.6 (Vin); also elsewhere on the board
VBAT_ALWON: Q2.2 (S), SW9.1 (A); also elsewhere on the board
VIO: C24.1, R24.1, U6.3 (VIN); also elsewhere on the board

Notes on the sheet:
LDO dropout voltage is 0.3-0.7V... so we need 2.8-3.2V of input. Not enough margin with just 2 AA cells: If any, NiMHs will break this (2.4V max). Hence, we need a SMPS to generate the 3.3VIO, and from that derive the 2.5V Vaux.
Note: M3406 and XR1151 are Chinesium, but very cheap and plenty good.
1V1: 500mA max
2V5: 200mA max (Note it draws from VIO)
L2: 1-4.7uH, 50-150mR (is 4.7uH, 0.479mR)
VIO: 3.3V @ 700mA max
5V: 500mA max
Reverse polarity protection
Battery voltage measurement

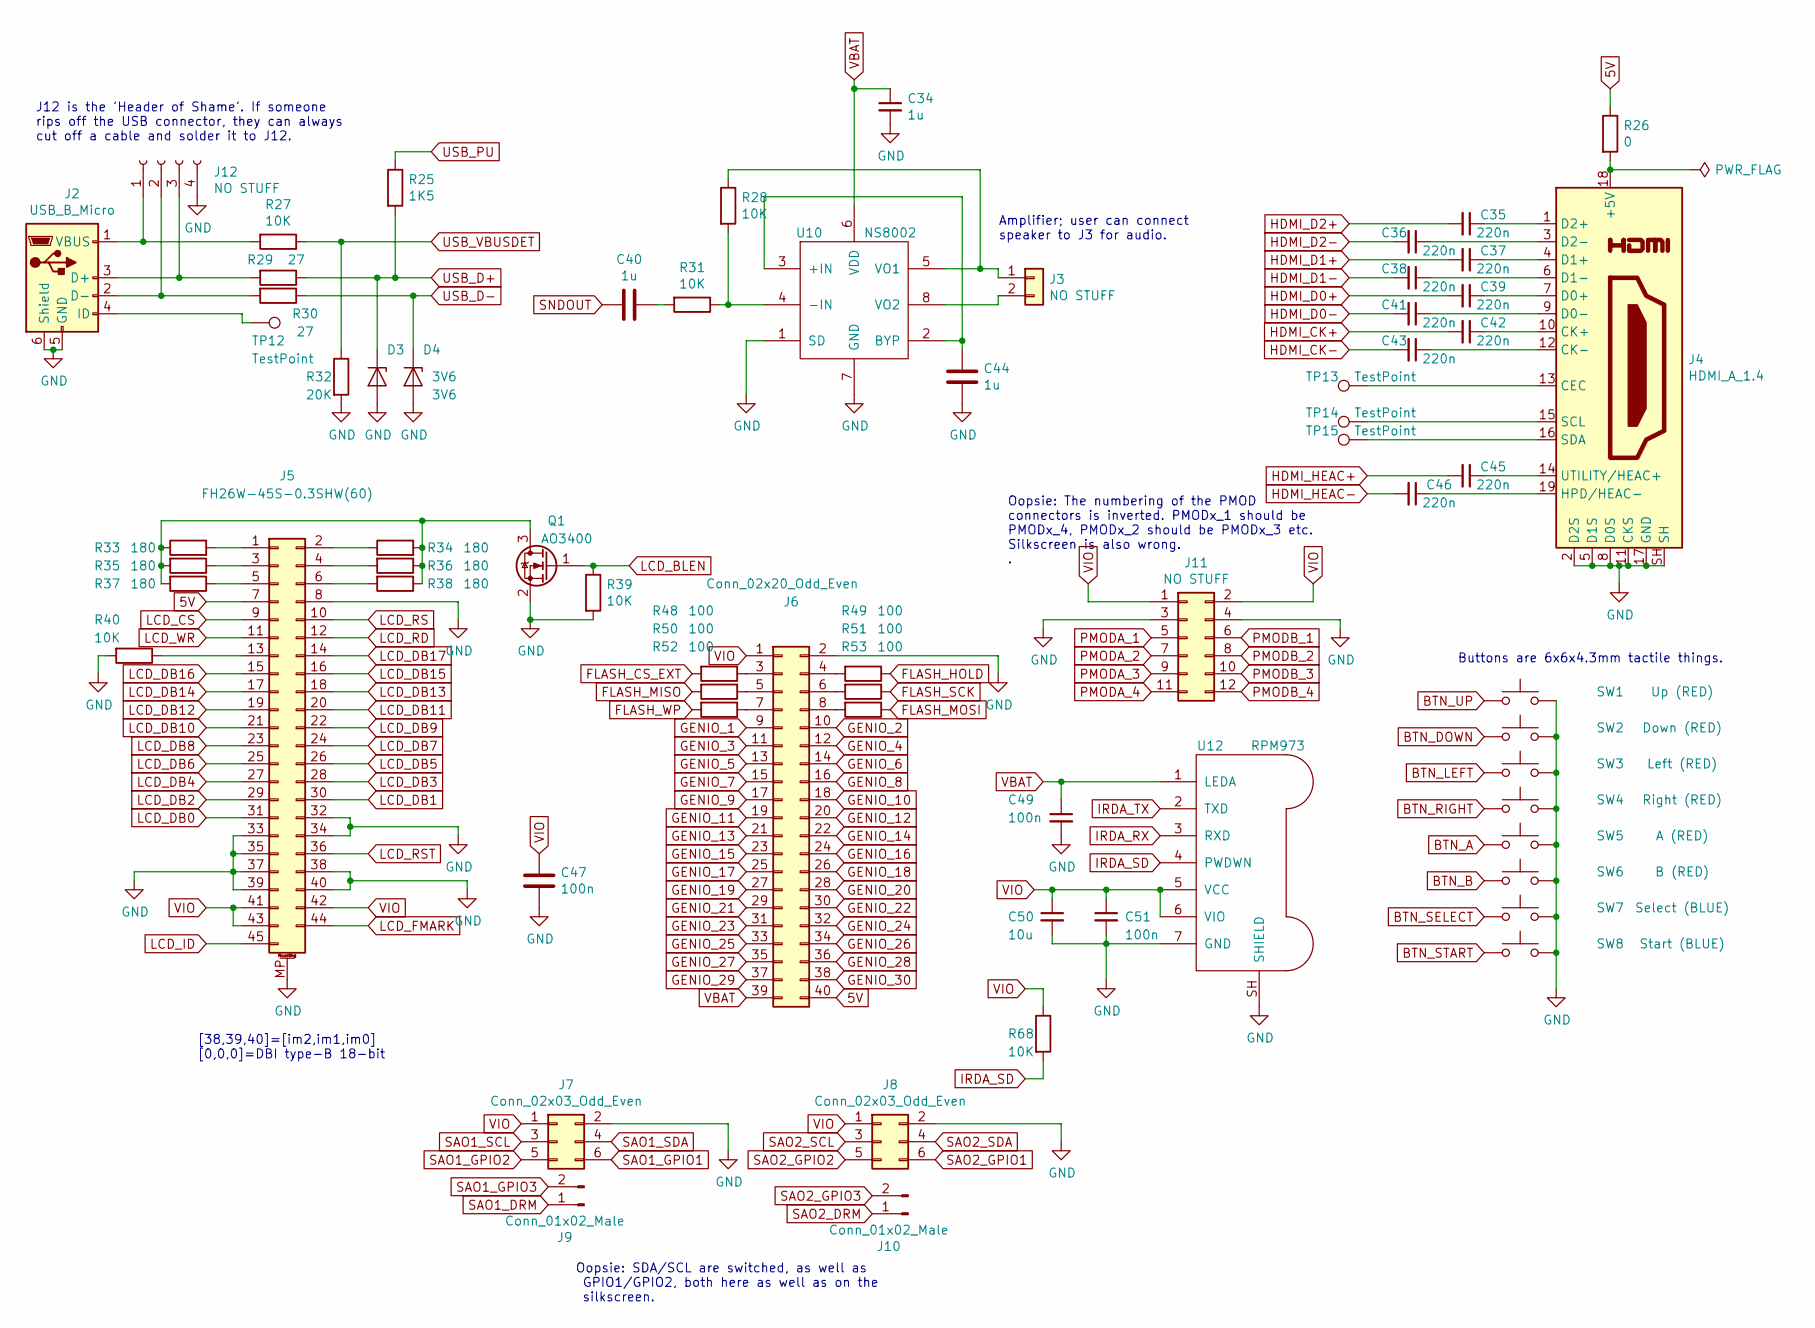
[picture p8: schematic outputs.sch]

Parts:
C34, C40, C44: 1u; C_0603_1608Metric
C35, C36, C37, C38, C39, C41, C42, C43, C45, C46: 220n; C_0603_1608Metric
C47, C49, C51: 100n; C_0603_1608Metric
C50: 10u; C_0805_2012Metric
D3, D4: 3V6; D_SOD-323
J2: USB_B_Micro; USB_Micro-B_China_MK5P
J3: NO STUFF; PinSocket_1x02_P2.54mm_Vertical
J4: HDMI_A_1.4; Boom_Precision_HDMI-001
J5: FH26W-45S-0.3SHW(60); FH26-45S-0.3SHW
J6: Conn_02x20_Odd_Even; PinSocket_2x20_P2.54mm_Horizontal
J7, J8: Conn_02x03_Odd_Even; PinSocket_2x03_P2.54mm_Vertical
J9, J10: Conn_01x02_Male; PinHeader_1x02_P2.54mm_Vertical
J11: NO STUFF; PinSocket_2x06_P2.54mm_Horizontal
J12: NO STUFF; PinHeader_1x04_P2.54mm_Vertical
Q1: AO3400; SOT-23
R25: 1K5; R_0603_1608Metric
R26: 0; R_0603_1608Metric
R27, R28, R31, R39, R40, R68: 10K; R_0603_1608Metric
R29, R30: 27; R_0603_1608Metric
R32: 20K; R_0603_1608Metric
R33, R34, R35, R36, R37, R38: 180; R_0603_1608Metric
R48, R49, R50, R51, R52, R53: 100; R_0603_1608Metric
SW1: Up (RED); SW_Push_1P1T_NO_6x6mm_H9.5mm
SW2: Down (RED); SW_Push_1P1T_NO_6x6mm_H9.5mm
SW3: Left (RED); SW_Push_1P1T_NO_6x6mm_H9.5mm
SW4: Right (RED); SW_Push_1P1T_NO_6x6mm_H9.5mm
SW5: A (RED); SW_Push_1P1T_NO_6x6mm_H9.5mm
SW6: B (RED); SW_Push_1P1T_NO_6x6mm_H9.5mm
SW7: Select (BLUE); SW_Push_1P1T_NO_6x6mm_H9.5mm
SW8: Start (BLUE); SW_Push_1P1T_NO_6x6mm_H9.5mm
TP12, TP13, TP14, TP15: TestPoint; TestPoint_Pad_D1.0mm
U10: NS8002; SSOP-8_3.9x5.05mm_P1.27mm
U12: RPM973; RPM973-H11

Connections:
5V: J5.7, J6.40, R26.1; also elsewhere on the board
BTN_A: SW5.1; also elsewhere on the board
BTN_B: SW6.1; also elsewhere on the board
BTN_DOWN: SW2.1; also elsewhere on the board
BTN_LEFT: SW3.1; also elsewhere on the board
BTN_RIGHT: SW4.1; also elsewhere on the board
BTN_SELECT: SW7.1; also elsewhere on the board
BTN_START: SW8.1; also elsewhere on the board
BTN_UP: SW1.1; also elsewhere on the board
FLASH_CS_EXT: R48.2; also elsewhere on the board
FLASH_HOLD: R49.1; also elsewhere on the board
FLASH_MISO: R50.2; also elsewhere on the board
FLASH_MOSI: R53.1; also elsewhere on the board
FLASH_SCK: R51.1; also elsewhere on the board
FLASH_WP: R52.2; also elsewhere on the board
GENIO_1: J6.9; also elsewhere on the board
GENIO_2: J6.10; also elsewhere on the board
GENIO_3: J6.11; also elsewhere on the board
GENIO_4: J6.12; also elsewhere on the board
GENIO_5: J6.13; also elsewhere on the board
GENIO_6: J6.14; also elsewhere on the board
GENIO_7: J6.15; also elsewhere on the board
GENIO_8: J6.16; also elsewhere on the board
GENIO_9: J6.17; also elsewhere on the board
GENIO_10: J6.18; also elsewhere on the board
GENIO_11: J6.19; also elsewhere on the board
GENIO_12: J6.20; also elsewhere on the board
GENIO_13: J6.21; also elsewhere on the board
GENIO_14: J6.22; also elsewhere on the board
GENIO_15: J6.23; also elsewhere on the board
GENIO_16: J6.24; also elsewhere on the board
GENIO_17: J6.25; also elsewhere on the board
GENIO_18: J6.26; also elsewhere on the board
GENIO_19: J6.27; also elsewhere on the board
GENIO_20: J6.28; also elsewhere on the board
GENIO_21: J6.29; also elsewhere on the board
GENIO_22: J6.30; also elsewhere on the board
GENIO_23: J6.31; also elsewhere on the board
GENIO_24: J6.32; also elsewhere on the board
GENIO_25: J6.33; also elsewhere on the board
GENIO_26: J6.34; also elsewhere on the board
GENIO_27: J6.35; also elsewhere on the board
GENIO_28: J6.36; also elsewhere on the board
GENIO_29: J6.37; also elsewhere on the board
GENIO_30: J6.38; also elsewhere on the board
GND: C34.2, C44.2, C47.2, C49.2, C50.2, C51.2, D3.2 (A), D4.2 (A), J2.5 (GND), J2.6 (Shield), J4.2 (D2S), J4.5 (D1S), J4.8 (D0S), J4.11 (CKS), J4.17 (GND), J4.SH, J5.8, J5.32, J5.33, J5.34, J5.35, J5.37, J5.38, J5.39, J5.40, J5.MP (MountPin), J6.2, J7.2, J8.2, J11.3, J11.4, J12.4, Q1.2 (S), R32.2, R39.2, R40.2, SW1.2, SW2.2, SW3.2, SW4.2, SW5.2, SW6.2, SW7.2, SW8.2, U10.1 (SD), U10.7 (GND), U12.7 (GND), U12.SH (SHIELD); also elsewhere on the board
HDMI_CK+: C42.2; also elsewhere on the board
HDMI_CK-: C43.2; also elsewhere on the board
HDMI_D0+: C39.2; also elsewhere on the board
HDMI_D0-: C41.2; also elsewhere on the board
HDMI_D1+: C37.2; also elsewhere on the board
HDMI_D1-: C38.2; also elsewhere on the board
HDMI_D2+: C35.2; also elsewhere on the board
HDMI_D2-: C36.2; also elsewhere on the board
HDMI_HEAC+: C45.2; also elsewhere on the board
HDMI_HEAC-: C46.2; also elsewhere on the board
IRDA_RX: U12.3 (RXD); also elsewhere on the board
IRDA_SD: R68.2, U12.4 (PWDWN); also elsewhere on the board
IRDA_TX: U12.2 (TXD); also elsewhere on the board
LCD_BLEN: Q1.1 (G), R39.1; also elsewhere on the board
LCD_CS: J5.9; also elsewhere on the board
LCD_DB0: J5.31; also elsewhere on the board
LCD_DB1: J5.30; also elsewhere on the board
LCD_DB2: J5.29; also elsewhere on the board
LCD_DB3: J5.28; also elsewhere on the board
LCD_DB4: J5.27; also elsewhere on the board
LCD_DB5: J5.26; also elsewhere on the board
LCD_DB6: J5.25; also elsewhere on the board
LCD_DB7: J5.24; also elsewhere on the board
LCD_DB8: J5.23; also elsewhere on the board
LCD_DB9: J5.22; also elsewhere on the board
LCD_DB10: J5.21; also elsewhere on the board
LCD_DB11: J5.20; also elsewhere on the board
LCD_DB12: J5.19; also elsewhere on the board
LCD_DB13: J5.18; also elsewhere on the board
LCD_DB14: J5.17; also elsewhere on the board
LCD_DB15: J5.16; also elsewhere on the board
LCD_DB16: J5.15; also elsewhere on the board
LCD_DB17: J5.14; also elsewhere on the board
LCD_FMARK: J5.44; also elsewhere on the board
LCD_ID: J5.45; also elsewhere on the board
LCD_RD: J5.12; also elsewhere on the board
LCD_RS: J5.10; also elsewhere on the board
LCD_RST: J5.36; also elsewhere on the board
LCD_WR: J5.11; also elsewhere on the board
unnamed: C35.1, J4.1 (D2+)
unnamed: C36.1, J4.3 (D2-)
unnamed: C37.1, J4.4 (D1+)
unnamed: C38.1, J4.6 (D1-)
unnamed: C39.1, J4.7 (D0+)
unnamed: C40.1, R31.2
unnamed: C41.1, J4.9 (D0-)
unnamed: C42.1, J4.10 (CK+)
unnamed: C43.1, J4.12 (CK-)
unnamed: C44.1, U10.2 (BYP), U10.3 (+IN)
unnamed: C45.1, J4.14 (UTILITY/HEAC+)
unnamed: C46.1, J4.19 (HPD/HEAC-)
unnamed: J2.4 (ID), TP12.1
unnamed: J3.1, R28.1, U10.5 (VO1)
unnamed: J3.2, U10.8 (VO2)
unnamed: J4.13 (CEC), TP13.1
unnamed: J4.15 (SCL), TP14.1
unnamed: J4.16 (SDA), TP15.1
unnamed: J4.18 (+5V), R26.2
unnamed: J5.1, R33.2
unnamed: J5.2, R34.1
unnamed: J5.3, R35.1
unnamed: J5.4, R36.2
unnamed: J5.5, R37.1
unnamed: J5.6, R38.2
unnamed: J5.13, R40.1
unnamed: J6.3, R48.1
unnamed: J6.4, R49.2
unnamed: J6.5, R50.1
unnamed: J6.6, R51.2
unnamed: J6.7, R52.1
unnamed: J6.8, R53.2
unnamed: J2.1 (VBUS), J12.1, R27.2
unnamed: J2.2 (D-), J12.2, R30.2
unnamed: J2.3 (D+), J12.3, R29.2
unnamed: Q1.3 (D), R33.1, R34.2, R35.2, R36.1, R37.2, R38.1
unnamed: R28.2, R31.1, U10.4 (-IN)
PMODA_1: J11.5; also elsewhere on the board
PMODA_2: J11.7; also elsewhere on the board
PMODA_3: J11.9; also elsewhere on the board
PMODA_4: J11.11; also elsewhere on the board
PMODB_1: J11.6; also elsewhere on the board
PMODB_2: J11.8; also elsewhere on the board
PMODB_3: J11.10; also elsewhere on the board
PMODB_4: J11.12; also elsewhere on the board
SAO1_DRM: J9.1; also elsewhere on the board
SAO1_GPIO1: J7.6; also elsewhere on the board
SAO1_GPIO2: J7.5; also elsewhere on the board
SAO1_GPIO3: J9.2; also elsewhere on the board
SAO1_SCL: J7.3; also elsewhere on the board
SAO1_SDA: J7.4; also elsewhere on the board
SAO2_DRM: J10.1; also elsewhere on the board
SAO2_GPIO1: J8.6; also elsewhere on the board
SAO2_GPIO2: J8.5; also elsewhere on the board
SAO2_GPIO3: J10.2; also elsewhere on the board
SAO2_SCL: J8.3; also elsewhere on the board
SAO2_SDA: J8.4; also elsewhere on the board
SNDOUT: C40.2; also elsewhere on the board
USB_D+: D3.1 (K), R25.2, R29.1; also elsewhere on the board
USB_D-: D4.1 (K), R30.1; also elsewhere on the board
USB_PU: R25.1; also elsewhere on the board
USB_VBUSDET: R27.1, R32.1; also elsewhere on the board
VBAT: C34.1, C49.1, J6.39, U10.6 (VDD), U12.1 (LEDA); also elsewhere on the board
VIO: C47.1, C50.1, C51.1, J5.41, J5.42, J5.43, J6.1, J7.1, J8.1, J11.1, J11.2, R68.1, U12.5 (VCC), U12.6 (VIO); also elsewhere on the board

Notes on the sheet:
[38,39,40]=[im2,im1,im0] [0,0,0]=DBI type-B 18-bit
Amplifier; user can connect speaker to J3 for audio.
J12 is the 'Header of Shame'. If someone rips off the USB connector, they can always cut off a cable and solder it to J12.
Buttons are 6x6x4.3mm tactile things.
Oopsie: SDA/SCL are switched, as well as GPIO1/GPIO2, both here as well as on the silkscreen.
Oopsie: The numbering of the PMOD connectors is inverted. PMODx_1 should be PMODx_4, PMODx_2 should be PMODx_3 etc. Silkscreen is also wrong. .

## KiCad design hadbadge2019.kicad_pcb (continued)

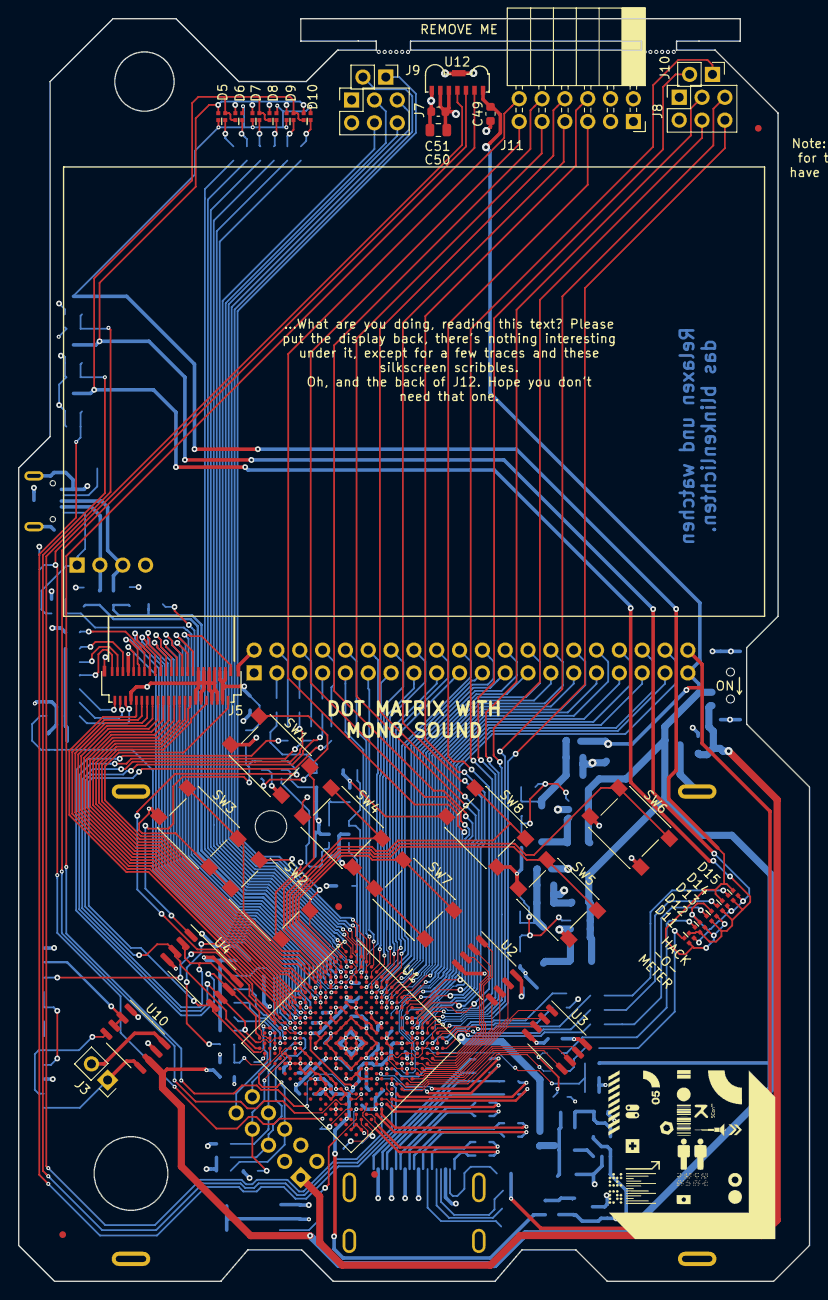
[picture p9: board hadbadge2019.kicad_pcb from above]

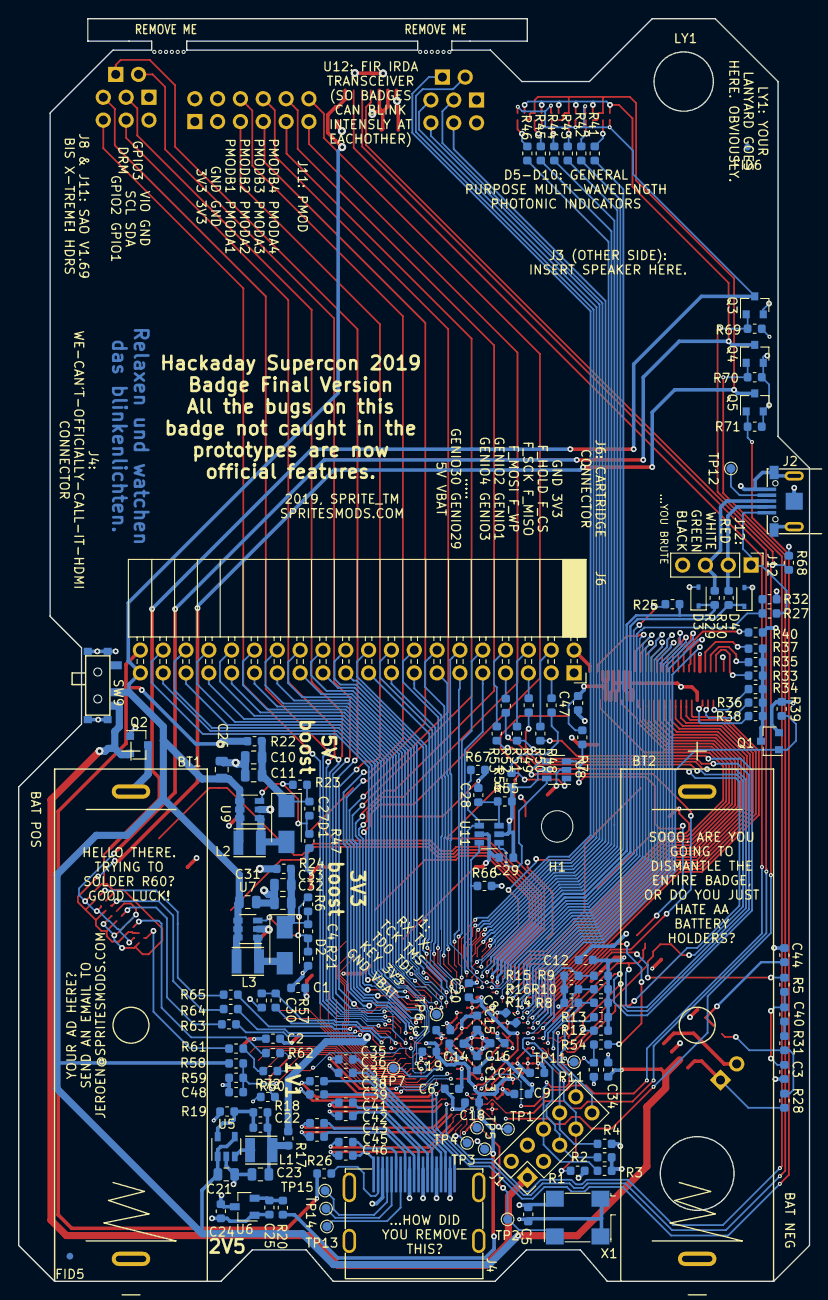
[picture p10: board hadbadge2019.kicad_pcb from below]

Board: 4 copper layers, 88.0 x 140.5 mm, 202 parts (162 on the bottom side), 235 nets.

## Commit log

2019-02-24 Initial commit. Nearly done with design.
    [FPGA.sch, hadbadge2019.kicad_pcb, hadbadge2019.sch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]
2019-05-18 Proto 1
    [FPGA.sch, hadbadge2019.kicad_pcb, outputs.sch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]
2019-06-02 New design
    [FPGA.sch, hadbadge2019.kicad_pcb, hadbadge2019.sch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]
2019-06-11 WiP for proto 2
    [FPGA.sch, hadbadge2019.kicad_pcb, outputs.sch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]
2019-06-16 Nearly done...
    [FPGA.sch, hadbadge2019.kicad_pcb, outputs.sch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]
2019-06-27 Proto2, final version
    [FPGA.sch, hadbadge2019-bom.csv, hadbadge2019.kicad_pcb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]
2019-06-29 Fix fab drawings to make sense
    [FPGA.sch, hadbadge2019-bom.csv, hadbadge2019.kicad_pcb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]
2019-08-15 No idea what these tiny differences are... Done with proto 2, prepare for proto 3!
    [hadbadge2019.kicad_pcb]
2019-09-15 This is proto 3.
    [FPGA.sch, hadbadge2019.kicad_pcb, hadbadge2019.sch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]
2019-09-15 Starting to add fixes for final ver
    [FPGA.sch, hadbadge2019.kicad_pcb, power.sch]
2019-09-18 Final version
    [hadbadge2019.kicad_pcb]
2019-09-18 Final changes: add some fiducials, clean up vias. Ready for prod, I hope.
    [hadbadge2019.kicad_pcb, outputs.sch, power.sch]
2019-11-05 Note oopsie in scl/sda
    [hadbadge2019.sch, outputs.sch]
2019-11-10 Add schematics and README.
    [outputs.sch, power.sch]
2019-11-10 Add known issues
    [hadbadge2019.kicad_pcb, outputs.sch]
